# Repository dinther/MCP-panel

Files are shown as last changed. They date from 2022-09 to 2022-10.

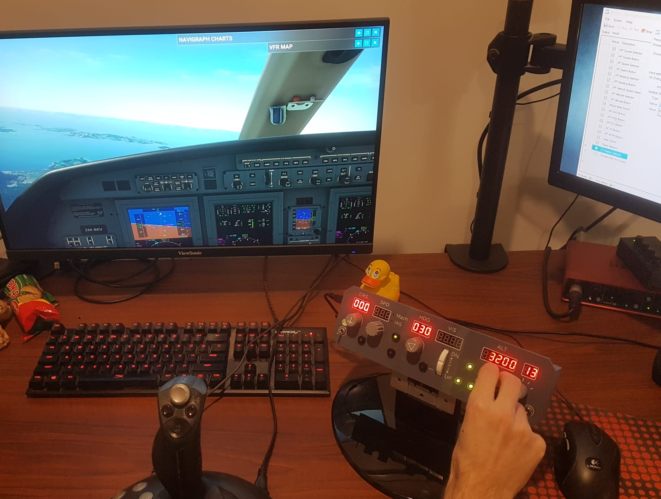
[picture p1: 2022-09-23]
images/panel_in_use_on_cj4_in_msfs2020.jpg

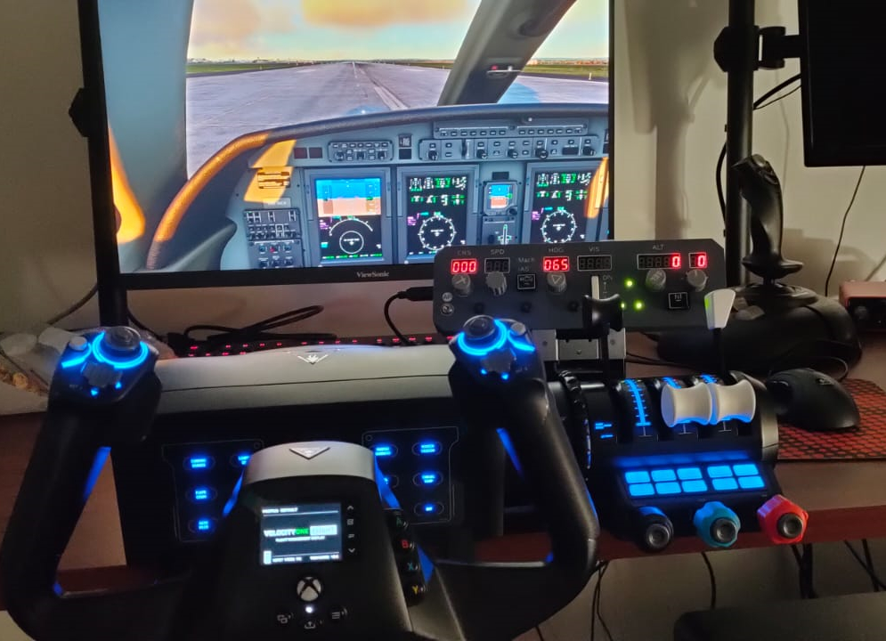
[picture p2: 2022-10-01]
images/Microsoft Flight simulator flying the custom CJ4.jpg

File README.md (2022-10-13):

# MCP-panel

This project shows how to make a control panel with various switches, displays and encoders that can be used in conjuction with Microsoft Flight simulator or other flight simulator programs such as XPlane or DCS (Combat Flight Simulator)

You can write your own software interface or save yourself the pain and simply use the excellent free and open source Mobiflight software https://www.mobiflight.com/
Included in the project is a complete mobiflight definition file for Microsoft Flight Simulator and the cudstom CJ4 aircraft.





3D print your own MCP panel for flight simulator.



Actual printed panels.



## wiring

I wired all switches and encoders to pull the input pin down to ground. This means that the arduino input pins are configured to "INPUT_PULLUP" in mobiflight.

## Hardware used

For convenience I sourced my parts from a local electronics store. Not cheap but I link it here so you can get the details of the parts and source them where you wish.

### Arduino Mega

The one I used is a clone but Mobiflight recognized it without any issues.



https://www.jaycar.co.nz/duinotech-mega-2560-r3-board-for-arduino/p/XC4420

### Segmented displays
I used three 8 digit 7 segment displays. They only had red ones but ideally you want white ones.
The panel is designed to accomodate these displays but these parameters can be changed in OpenSCAD.
You only need three outputs for the all the displays as they are linked.



Tip: Pick the ones where the two display componets are soldered on straight. I noticed many of these displayed online are crooked. However, I did design in some leeway in the 3D panel to accomodate this.

https://www.jaycar.co.nz/8-digit-7-segment-display-module/p/XC3714

### Tactile push buttons
These momentary pushbuttons have build in LED's in red, green and blue. They are small and cheap and with a 3D printed custom face attached they can show whatever back-lit caption you want. The panel has slots designed for 5 of these buttons that should fit tight.


https://www.jaycar.co.nz/spst-pcb-mount-tactile-switch-with-green-led/p/SP0621

### Rotary encoder

I actually used two types of encoders and the shafts were slightly different. The 5 panel holes are made to take either type. The encoders also have a push button function But the vertical wheel can not access the push button function. You need 3 inputs per LED.



https://www.jaycar.co.nz/rotary-encoder-with-pushbutton/p/SR1230

### Dual color 3mm LED's

The panel has 4 dual color (Red / Green) LED's. One is used behind a back-lit round label and the other three as Landing wheel indicators. You can actually also get Amber if you turn on both Red and Green. You need two outputs per LED



https://www.jaycar.co.nz/tricolour-red-green-orange-3mm-led-4-5-6mcd-round-diffused/p/ZD0249

### Toggle switches

The panel contains two toggle switches. Each switch requiring one input.



https://www.jaycar.co.nz/spdt-sub-miniature-toggle-switch-solder-tag/p/ST0300

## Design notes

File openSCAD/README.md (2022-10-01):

##  OpenSCAD
The cad files are made in openSCAD. https://openscad.org/ This is amazing free open source software where you create 3D cad models using a programming language rather than a user interface.
What makes this appoach amazing is that changes are easily managed as everything is pure code. 

The OpenSCAD UI has a customizer UI built in which can be used to make certain adjustments to the cad models without the need to code.

Nobody should commit his designs to closed source rent software such as fusion360 if at all avoidable.

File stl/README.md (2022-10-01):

## 3D Print instructions

It is best to generate your own STL files using the free and excellent openSCAD open source CAD software because then you can customize things like hole sizes, label captions and 3D print details such as layer heights.

But if not, then here are the details you will need to print these STL's.

### Hole test piece


- Material: same as what you intend to use for the Display panel
- color": any
- Nozzle: 0.4mm
- Layer height: 0.3mm
- Infill: 15%

Start with printing the hole test piece. It is a small object that can be 3D printed quickly. Use it to check if the hole sizes work with the components you have.

### Display lid

The display lid closes the back of the MCP box and is designed to hold the Arduino Mega board. There are pegs that slot into the PCB holes. No screws are required as the wires press onto and hold the board in place.
Print it with the back flat on the build plate.

- Material: PLA (PETG if used in hot environments)
- Color: gray
- Nozzle: 0.4mm
- Layer height: 0.3mm
- Infill: 15%

### Display panel
The main panel is a composite of two material colors. There is the main body in gray and the text and symbol inlays in white.



Load the main body into the slicer and place it with the face (Text side) down on the build plate. Then import the display panel text stl and also place it face down on the build plate.
Align the two objects as accurately as possible.

You can allocate a different extruder to each object. I will write a tutorial later on how to create amazing dual material panel prints later.

- Material: PLA (PETG if used in hot environments)
- Color: gray / white
- Nozzle: 0.4mm
- Layer height: 0.3mm
- Infill: 15%

### Pushbutton caps

In order to get nice captions on your push buttons you can use this 3D model. The base clamps onto a tacktile push button and a cap snaps onto the base with whatever caption you want.



The caps are printed in two different color PLA. The white lettering is actually a solid white surface at the back and ponting at the LED in the push button. This allows the white details to emit some light.



STL file comes with these captions but you can define what ever you want in the openSCAD file.

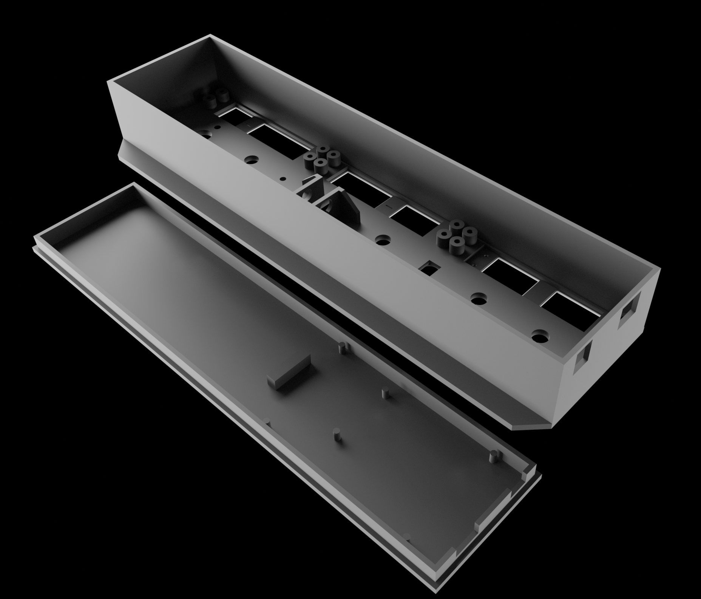
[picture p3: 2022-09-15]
images/display_panel_inside.png

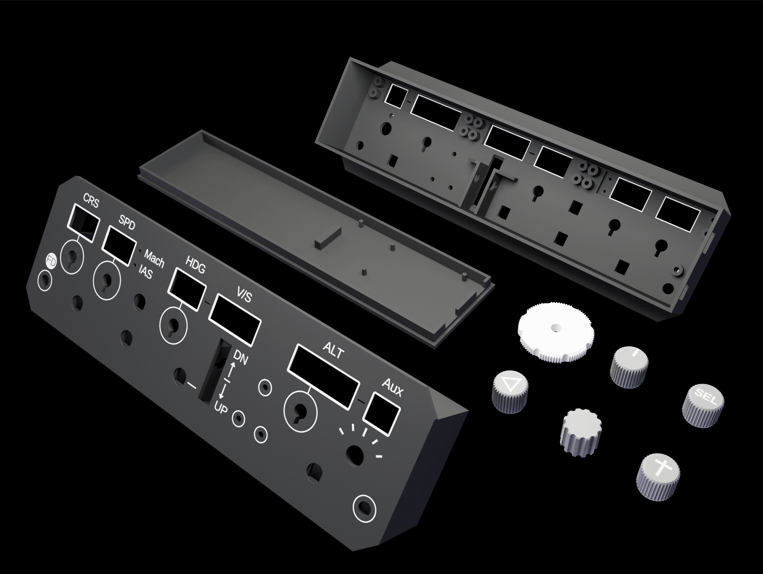
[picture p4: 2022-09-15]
images/display_panel.png

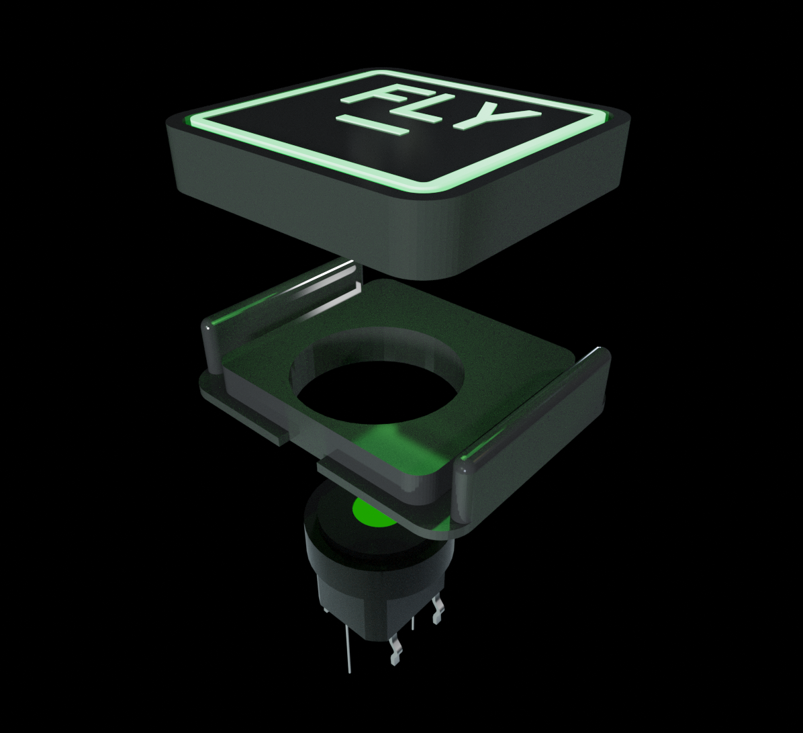
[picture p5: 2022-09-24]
images/pushbutton_cap_system.png

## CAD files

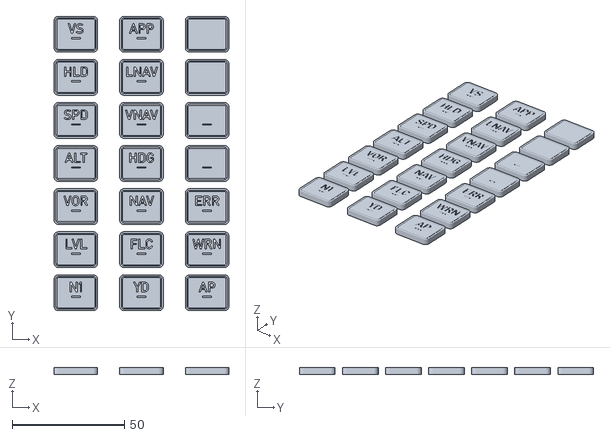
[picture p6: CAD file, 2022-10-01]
stl/MPC_button_caps_0.2_glue_on.stl
78.0 x 131.2 x 2.90

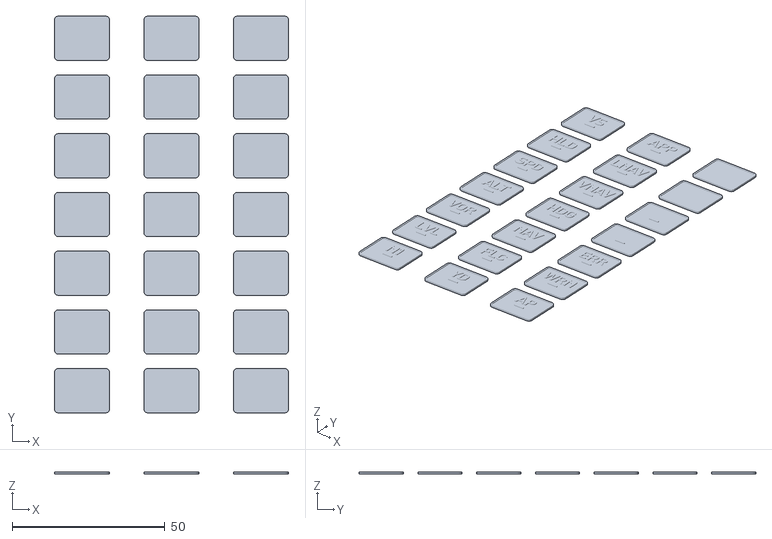
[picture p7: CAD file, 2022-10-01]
stl/MPC_pushbutton_caps_inlay_0.2_glue_on.stl
76.5 x 129.7 x 0.8

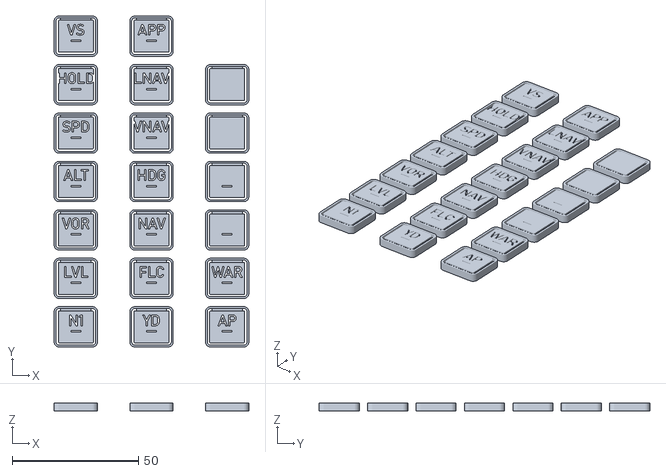
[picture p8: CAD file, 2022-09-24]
stl/MPC_pushbutton_caps.stl
77.2 x 131.2 x 3.10

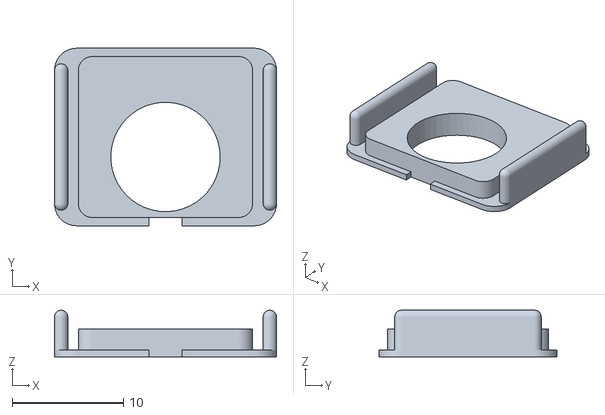
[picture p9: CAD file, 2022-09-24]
stl/MPC_pushbuttons_base.stl
20.0 x 16.0 x 4.20

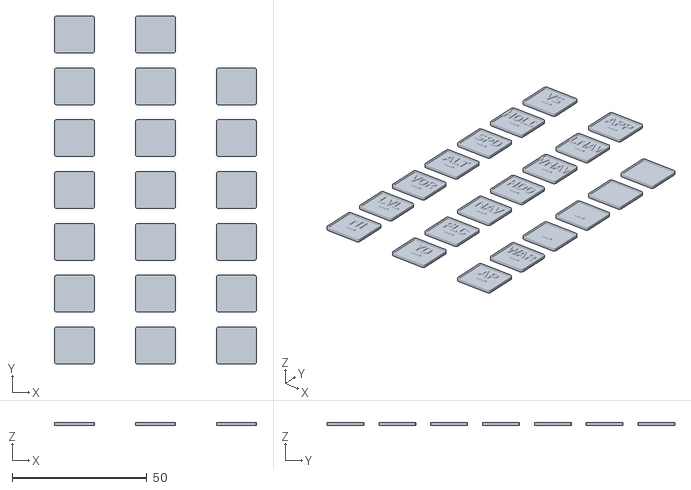
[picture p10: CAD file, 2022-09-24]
stl/MPC_pushbutton_caps_inlay.stl
74.9 x 128.9 x 1.20

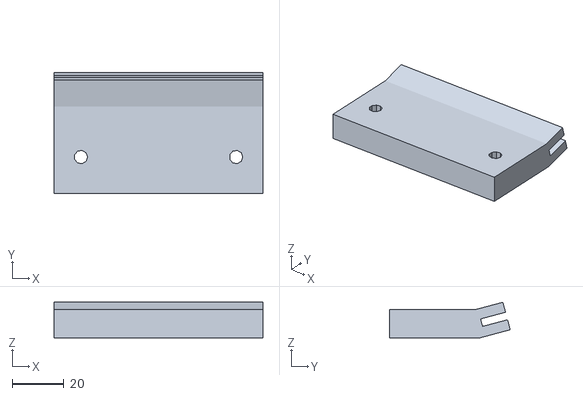
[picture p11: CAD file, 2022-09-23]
stl/mounting_plate_Tom_monitor_stand.stl
80.8 x 46.6 x 13.7

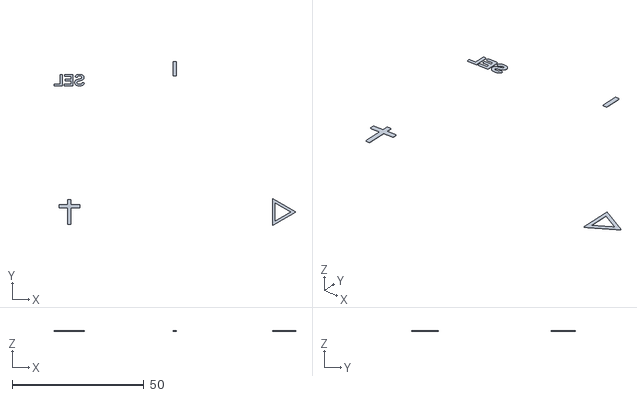
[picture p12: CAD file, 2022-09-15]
stl/MCP_knob_inlays.stl
91.8 x 62.4 x 0.3

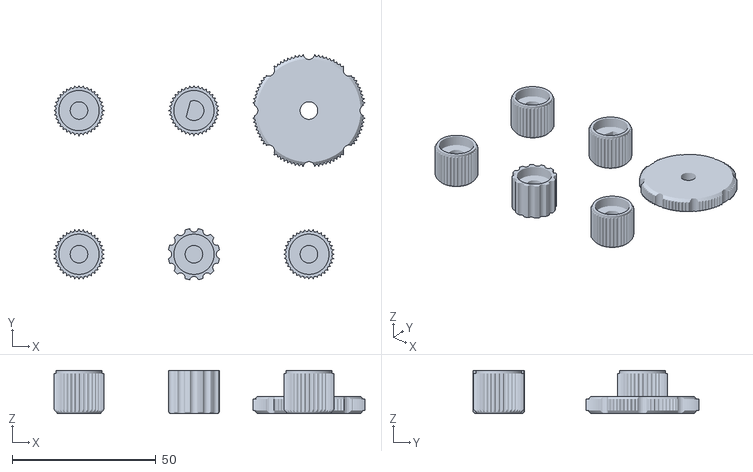
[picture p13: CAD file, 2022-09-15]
stl/MCP_knobs.stl
108.2 x 78.5 x 15.0

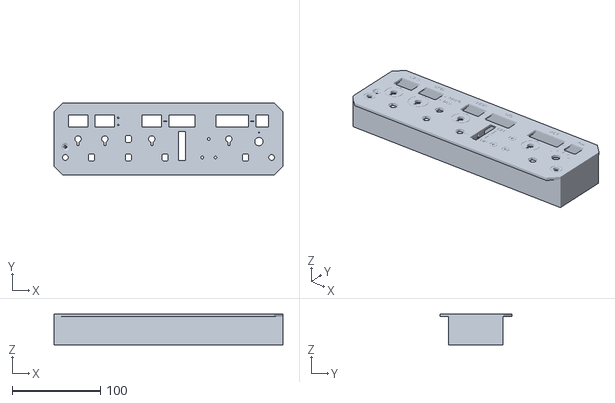
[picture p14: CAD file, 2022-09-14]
stl/display_panel.stl
260.1 x 82.0 x 35.0

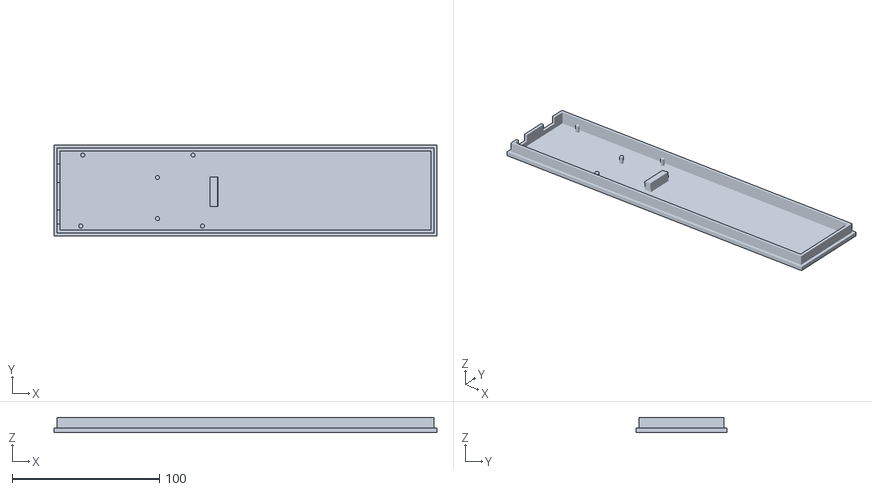
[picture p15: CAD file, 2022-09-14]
stl/display_panel_lid.stl
260.1 x 61.5 x 10.0

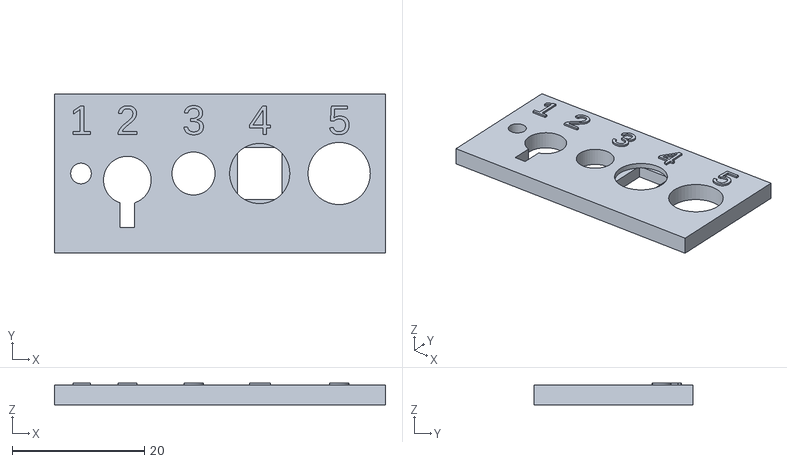
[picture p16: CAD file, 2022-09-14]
stl/hole_test_piece.stl
50.0 x 24.0 x 3.30

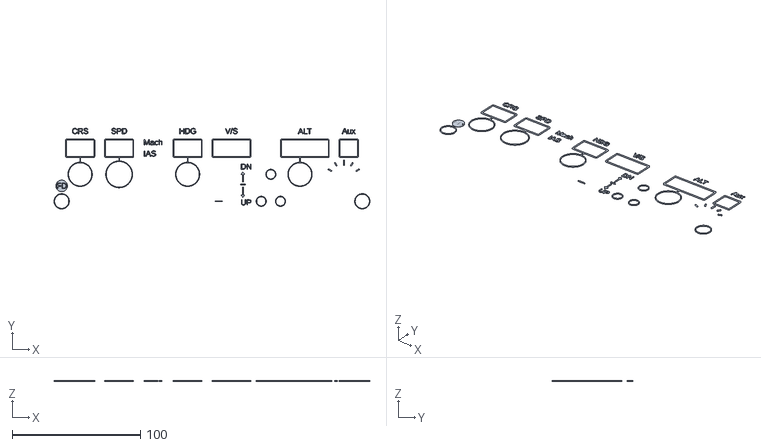
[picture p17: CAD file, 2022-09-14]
stl/display_panel_text.stl
246.1 x 63.1 x 0.6

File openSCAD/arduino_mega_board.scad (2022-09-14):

l = 101.6;
w = 53.3;
t = 1.6;
$fn=45;

module arduino_mega_pcb_holes(diameter = 3.2, height = 1.6){
    translate([13.97, 2.54, 0]) cylinder(d=diameter,h=height);
    translate([15.3, 50.7, 0])  cylinder(d=diameter,h=height);
    translate([66.1, 35.5, 0])  cylinder(d=diameter,h=height);
    translate([66.1, 35.5, 0])  cylinder(d=diameter,h=height);
    translate([66.1, 7.6, 0])   cylinder(d=diameter,h=height);
    translate([90.2, 50.7, 0])  cylinder(d=diameter,h=height);
    translate([96.52, 2.52, 0]) cylinder(d=diameter,h=height);
}

module arduino_mega_pcb(){
    b = 2.8;
    difference(){
        linear_extrude(t) polygon([[0,0],[l-b,0],[l-b,1],[l,1 + b],[l,1 + b + 35],[l-b, 1 + b + 35 + b],[l-b,w-2],[l-b-2,w],[0,w]]);
        //  PCB holes
        translate([0,0,-1]) arduino_mega_pcb_holes(3.2, t + 2);
    }
}

module arduino_mega_headers(){
    translate([17.6,w-3.9,t]) cube([25.6, 2.3, 8.9]);
    translate([44.6,w-3.9,t]) cube([20.5, 2.3, 8.9]);
    translate([67,w-3.9,t]) cube([20.5, 2.3, 8.9]);
    
    translate([26.1,1.8,t]) cube([20.5, 2.3, 8.9]);
    translate([49,1.8,t]) cube([20.5, 2.3, 8.9]);
    translate([72.3,1.8,t]) cube([20.5, 2.3, 8.9]);
    
    translate([93,6.4,t]) cube([4.8,45.9, 8.9]);
    
    translate([15.1,w-9.6,t]) cube([7.2, 5, 8.9]);
    translate([62.5, 24.6,t]) cube([5, 7.2, 8.9]);   
}

module arduino_mega_components(){
    //  cpu
    translate([43.1,21.3,t]) color("#111111") cube([13.4, 13.4, 1.3]);
    //  button
    translate([70.8,24.8,t]) color("silver") cube([6.3, 6.3, 2.1]);
    translate([73.95,27.95,t+2.1]) color("red") cylinder(d = 2.8, h = 0.9);
}

module arduino_mega_USB_plug(){
    translate([-6.3,32.3,t]) color("silver") cube([16.1,12,10.6]);
}

module arduino_mega_USB_plug_cut(){  //  0.5mm oversized for hole cutting
    translate([-6.3,32.05,t-0.25]) color("silver") cube([16.1,12.5,11.1]);
}

module arduino_mega_DC_plug_cut(){  //  0.5mm oversized for hole cutting
    translate([-4.7,3.95,t-0.25]){ cube([6,9.3,11.1]); }    
}

module arduino_mega_DC_plug(){
    color("#111111") difference(){
        union(){
            translate([-1.7,4.2,t]){ cube([13.6,8.8,6.2]); cube([3,8.8,10.6]); }
            translate([-1.7,8.6,t+6.2]) rotate([0,90,0]) cylinder(d=8.8, h=13.6);
        }
        translate([-1.71,8.6,t+6.2]) rotate([0,90,0]) cylinder(d=6.2, h=11.6);
    }
    translate([1,8.6,t+6.2]) rotate([0,90,0]) color("silver") cylinder(d=1.3, h=8);
}

module arduino_mega(){
    color("blue") arduino_mega_pcb();
    color("#111111") arduino_mega_headers();
    arduino_mega_USB_plug();
    arduino_mega_DC_plug();
    arduino_mega_components();
}

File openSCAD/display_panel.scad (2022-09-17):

use <standard_holes.scad>;
use <arduino_mega_board.scad>;
include <8_digit_7_segment_max9219_display_module.scad>;

/* [General] */
$fn = 45;
// distance between the face plate and back wall
depth = 35;
//  Face plate thickness
thickness = 3;
//  Thickness of side walls
wall = 2;
font = "Bahnschrift:style=Light";
//font = "Liberation Sans:style=Normal";
//font = "Liberation Sans:style=Light";
//font = "Liberation Sans:style=Bold";
//  Height of the text font. Beware of 3D printer limitations.
text_size = 4.5;
//  layer height you intend to use for the slicer.
layer_height = 0.3;
//  Thickness of inlay in terms of print layers.
face_layers = 2;

/* [Text labels] */
display_1_text = "CRS";
display_2_text = "SPD";
display_3_text = "HDG";
display_4_text = "V/S";
display_5_text = "ALT";
display_6_text = "Aux";
lit_panel_text = "FD";
display_led_1_text = "Mach";
display_led_2_text = "IAS";
vertical_wheel_top_text = "DN";
vertical_wheel_bottom_text = "UP";


/* [Render] */
show_panel = true;
show_lid = true;
show_inlay = true;
show_hole_test = true;

/* [hidden] */
spacing = 23.0;
row_spacing = 13;
bottom_row = 10;
left_margin = 16;
right_margin = 16;
display_base = 44;
height = 72;
ridge = 0.35;

// 1 - digit, 0 - blank, 2 - two led's, 3 - minus sign only
display_slots_1 = [1,1,1,0,1,1,1,2];  //  CRS, SPD, Mach/IAS
display_slots_2 = [1,1,1,3,1,1,1,1];  //  HDG, V/S
display_slots_3 = [1,1,1,1,1,3,1,1];  //  ALT, Aux

//  helpful modules
module rsquare(s= [1,1], r=0.2, offset=0){
    x = s[0]*0.5;
    y = s[1]*0.5;
    offset(delta = offset)
    hull(){
        translate([-x,-y]) translate([r,r]) circle(r=r);
        translate([-x,y]) translate([r,-r]) circle(r=r);
        translate([x,y]) translate([-r,-r]) circle(r=r);
        translate([x,-y]) translate([-r,r]) circle(r=r);
    }
}

module ring(d1, d2){
    difference(){
        circle(d=d1);
        circle(d=d2);
    }
}

module tube(d1, d2, h){
    linear_extrude(h) ring(d1, d2);
}

module anglebracket(hole){
    t = 2;
    s = 8.5;
    d = 16;
    translate([-d*0.5, -s-t-t, 0]){
        difference(){
            translate([-12,0,0]) cube([t+d+t+12,s+t+t,s+t+t+1]);
            translate([t-14,-0.01,-0.01]) cube([d+14,s+t,s+t+4]);
            translate([-1,0,6]) rotate([40,0,0]) cube(d*2);
            translate([d*0.5+t,s+t-1,9]){
               if (is_num(hole) && (hole > 0)){
                   rotate([-90,0,0]) cylinder(d=hole, h=t*2);
               } else {
                   rotate([-90,180,0]) encoder_hole(thickness, 0.3);
               }
            }
        }
    }
}

module cut_out_shape(){
            fm = 0;
    union(){
        text_y = 4;
        //  display 1
        translate([left_margin + digit_width * 1.5, display_base+digit_height + text_y, 0])
        text(text = display_1_text, font = font, size = text_size, valign = "bottom", halign = "center");
        translate([left_margin + digit_width * 1.5, display_base + digit_height * 0.5, 0]) difference(){
            rsquare(s= [fm + digit_width * 3, fm + digit_height], r=1, offset=0);
            rsquare(s= [fm + digit_width * 3, fm + digit_height], r=1, offset=-0.75);
        }
        
        //  display 2
        translate([left_margin + digit_width * 5.5, display_base+digit_height + text_y, 0])
        text(text = display_2_text, font = font, size = text_size, valign = "bottom", halign = "center");
        translate([left_margin + digit_width * 5.5, display_base + digit_height * 0.5, 0]) difference(){
            rsquare(s= [fm + digit_width * 3,fm + digit_height], r=1, offset=0);
            rsquare(s= [fm + digit_width * 3,fm + digit_height], r=1, offset=-0.75);
        }
        
        //  display 3
        translate([left_margin + display_outer_width + spacing + digit_width * 1.5, display_base + digit_height + text_y, 0])
        text(text = display_3_text, font = font, size = text_size, valign = "bottom", halign = "center");
        translate([left_margin + display_outer_width + spacing + digit_width * 1.5, display_base + digit_height * 0.5, 0]) difference(){
            rsquare(s= [fm + digit_width * 3,fm + digit_height], r=1, offset=0);
            rsquare(s= [fm + digit_width * 3,fm + digit_height], r=1, offset=-0.75);
        }
        
        //  display 4
        translate([left_margin + display_outer_width + spacing + digit_width * 6, display_base + digit_height + text_y, 0])
        text(text = display_4_text, font = font, size = text_size, valign = "bottom", halign = "center");
        translate([left_margin + display_outer_width + spacing + digit_width * 6, display_base + digit_height * 0.5, 0]) difference(){
            rsquare(s= [fm + digit_width * 4,fm + digit_height], r=1, offset=0);
            rsquare(s= [fm + digit_width * 4,fm + digit_height], r=1, offset=-0.75);
        }

        //  display 5
        translate([left_margin + display_outer_width + spacing + display_outer_width + spacing + digit_width * 2.5, display_base + digit_height + text_y, 0])
        text(text = display_5_text, font = font, size = text_size, valign = "bottom", halign = "center");
        translate([left_margin + display_outer_width + spacing + display_outer_width + spacing + digit_width * 2.5, display_base + digit_height * 0.5, 0]) difference(){
            rsquare(s= [fm + digit_width * 5,fm + digit_height], r=1, offset=0);
            rsquare(s= [fm + digit_width * 5,fm + digit_height], r=1, offset=-0.75);
        }
        
        //  display 6
        translate([left_margin + display_outer_width + spacing + display_outer_width + spacing + digit_width * 7, display_base + digit_height + text_y, 0])
        text(text = display_6_text, font = font, size = text_size, valign = "bottom", halign = "center");
        translate([left_margin + display_outer_width + spacing + display_outer_width + spacing + digit_width * 7, display_base + digit_height * 0.5, 0]) difference(){
            rsquare(s= [fm + digit_width * 2,fm + digit_height], r=1, offset=0);
            rsquare(s= [fm + digit_width * 2,fm + digit_height], r=1, offset=-0.75);
        }

        //  vertical wheel labels
        translate([left_margin + display_outer_width + spacing + digit_width * 7.5, display_base-row_spacing+6, 0])
        text(text = vertical_wheel_top_text, font = font, size = text_size, valign = "center", halign = "center");

        translate([left_margin + display_outer_width + spacing + digit_width * 7.5, display_base-row_spacing-22, 0])
        text(text = vertical_wheel_bottom_text, font = font, size = text_size, valign = "center", halign = "center");
        
        //  arrow up down
        translate([left_margin + display_outer_width + spacing + digit_width * 7.5 -2.5, display_base-row_spacing-8, 0])
        polygon([[-0.3,2],[-0.3,8], [-1.5,8],[0,10],[1.5,8],[0.3,8],[0.3,2]]);
        translate([left_margin + display_outer_width + spacing + digit_width * 7.5 -2.5, display_base-row_spacing-8, 0])
        polygon([[-0.3,-2],[0.3,-2],[0.3,-8],[1.5,-8],[0,-10],[-1.5,-8],[-0.3,-8]]);
        translate([left_margin + display_outer_width + spacing + digit_width * 7.5 -4.5, display_base-row_spacing-8.3, 0])
        square([4,0.6]);


        //  display LED top
        translate([left_margin + display_outer_width, display_base + digit_height - 2.55, 0])
        text(text = display_led_1_text, font = font, size = text_size, valign = "center", halign = "left");

        //  display LED bottom
        translate([left_margin + display_outer_width, display_base + 3.15, 0])
        text(text = display_led_2_text, font = font, size = text_size, valign = "center", halign = "left");

        //  Lit panel text
        translate([13, bottom_row + 12, thickness - 0.6])
        difference(){
            circle(d=9);
            text(text = lit_panel_text, font = font, size = text_size, valign = "center", halign = "center");
        }
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

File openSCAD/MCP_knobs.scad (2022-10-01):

/* [General] */
$fn = 90;
outer_radius = 8;
shaft_radius = 3.06; //still to print and try
knob_height = 15;
layer_height = 0.15;
nut_cutout_height = 4;
nut_radius = 7.0;

ribble_radius = 0.5;
font = "Liberation Sans:style=Bold";
Altitude_caption = "SEL";
body_color = "silver"; //"whitesmoke";
inlay_color = "white"; //"dimgray";

/* [Render] */
Show_knobs = true;
Show_inlays = true;

module cap_carve(radius, x = 1.5, y = 1.5){
    difference(){
        translate([0,0,-1])color(body_color)cylinder(r=radius + 2, h=y+1);
         color(body_color)cylinder(r1=radius - x, r2=radius, h=y+0.01);
    }
}

module base_knob(radius, shaft, height, texture){
    difference(){
        union(){
            difference(){
                color(body_color) cylinder(r=radius, h=height);  //  body
                translate([0,0,3.0]) cylinder(r=shaft, h=height);    //  cut shaft
                translate([0,0,height - nut_cutout_height]) cylinder(r=nut_radius, h=nut_cutout_height+1);           //  cut space for nut
                
                if (texture == "carved"){
                    for (i =[0:30:360]) rotate([0,0,i]) translate([radius+0.25,0,0]) color(body_color) cylinder(r=ribble_radius*3, h=height, $fn=32);
                }
            }
            if (texture == "ribble"){
                for (i =[0:10:360]) rotate([0,0,i]) translate([radius+0.2,0,0]) color(body_color)cylinder(r=ribble_radius, h=height-1, $fn=3);
            }
        }
        translate([0,0,0]) cap_carve(radius+2, 2.5, 3);
    }
}

module selector_knob(radius, shaft, height){
    difference(){
        base_knob(radius = radius, shaft = 0, height = height, texture = "ribble");
        translate([0,0,height - nut_cutout_height]) cylinder(r=nut_radius, h=nut_cutout_height+1);
        translate([0,0,-0.1]) selector_decal(outer_radius, 0.1 + layer_height * 2);
        translate([0,0,3.0]) {
            //  Cut D shaft hole
            rotate([0,0,165]) intersection(){
                cylinder(r=shaft, h=height);    //  re-cut shaft
                translate([-shaft,-shaft,0]) cube([5.5, shaft *2, height+1]);
            }
        }
    }
}

module selector_decal(radius, height){
    difference(){
        color(inlay_color) translate([-1.3*0.5,outer_radius * 0.2, 0]) cube([1.3,outer_radius * 0.7, height]);
    }
}

module heading_knob(radius, shaft, height){
    difference(){
        base_knob(radius = radius, shaft = shaft, height = height, texture = "ribble");
        translate([0,0,-0.1]) heading_decal(outer_radius, 0.1 + layer_height * 2);
    }
}

module heading_decal(radius, height){
    difference(){
        color(inlay_color) cylinder(r=radius-2, h=height, $fn=3);
        translate([0,0,-1]) color(inlay_color) cylinder(r=radius-4, h=height+2, $fn=3);
    }
}

module course_knob(radius, shaft, height){   
difference(){
        base_knob(radius = radius, shaft = shaft, height = height, texture = "ribble");
        translate([0,0,-0.1]) course_decal(outer_radius, 0.1 + layer_height * 2);
    }
}

module course_decal(radius, height){
    w = 1.3;
    color(inlay_color) union(){
        translate([-outer_radius* 0.5,outer_radius * 0.2, 0]) cube([outer_radius, w, height]);
        translate([-w*0.5,- outer_radius * 0.6, 0]) cube([w,outer_radius * 1.2, height]);
    }
}

module altitude_knob(radius, shaft, height){
    difference(){
        base_knob(radius = radius, shaft = shaft, height = height, texture = "ribble");
        translate([0,0,-0.1]) altitude_decal(outer_radius, 0.1 + layer_height * 2, Altitude_caption);
    }
}

module altitude_decal(radius, height, text="SEL"){
    color(inlay_color) mirror([1,0,0]) linear_extrude(height) text(text=text, font = font, size=4.5, valign="center", halign="center");
}

module IAS_knob(radius, shaft, height){
    base_knob(radius = radius + 1, shaft = shaft, height = height, texture = "carved");
}


module VS_knob(radius, shaft, height, standoff=0){
    union(){
        difference(){
            union(){
                cylinder(r=radius, h=height);
                //  standoff
                cylinder(r=shaft +1, h=height + standoff); 
                for (i =[0:4:360]) rotate([0,0,i]) translate([radius+0.2,0,0]) cylinder(r=ribble_radius, h=height, $fn=3);   
            }
            for (i =[0:45:360]) rotate([0,0,i]) translate([radius+0.75,0,-0.5]) cylinder(r=ribble_radius*4, h=height+1, $fn=16);
            translate([0,0,0]) cap_carve(radius, 1, 1);
            translate([0,0,height]) rotate([180,0,0]) cap_carve(radius, 1, 1);
            translate([0,0,-1]) cylinder(r=shaft, h=height+2);
        }
        
    }
}

module knobs(){
    row = 50;
    col = 40;
    translate([col * 0, row * 0, 0]) course_knob(radius = outer_radius, shaft = shaft_radius, height = knob_height);
    translate([col * 1, row * 0, 0]) IAS_knob(radius = outer_radius, shaft = shaft_radius, height = knob_height);
    translate([col * 2, row * 0, 0]) heading_knob(radius = outer_radius, shaft = shaft_radius, height = knob_height);
    translate([col * 0, row * 1, 0]) altitude_knob(radius = outer_radius, shaft = shaft_radius, height = knob_height);
    translate([col * 1, row * 1, 0]) selector_knob(radius = outer_radius, shaft = shaft_radius + 0.4, height = knob_height);

    translate([col * 2, row * 1, 0]) VS_knob(radius = 19, shaft = shaft_radius, height = 6, standoff=1);
}

module inlays(){
    row = 50;
    col = 40;
    translate([col * 0, row * 0, 0]) course_decal(outer_radius, layer_height * 2);
    translate([col * 2, row * 0, 0]) heading_decal(outer_radius, layer_height * 2);
    translate([col * 0, row * 1, 0]) altitude_decal(outer_radius, layer_height * 2, Altitude_caption);
    translate([col * 1, row * 1, 0]) selector_decal(outer_radius, layer_height * 2);
}

if (Show_knobs) {
    knobs();
}
if (Show_inlays){
    inlays();
}

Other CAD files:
openSCAD/mounting_plate_Tom_monitor_stand.scad
openSCAD/8_digit_7_segment_max9219_display_module.scad
openSCAD/MPC_pushbuttons.scad
openSCAD/SPST_PCB_Mount_Tactile_Switch_with_LED.scad
openSCAD/standard_holes.scad

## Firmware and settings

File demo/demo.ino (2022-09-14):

//  MCP panel stand-alone demo
//  By: Paul van Dinther

//We always have to include the library
#include "LedControl.h"
#include "encoder.h"

#define DEBOUNCE 2

//  Segmented displays
#define MAX7219CS 22  //  segmented display CS (load) yellow
#define MAX7219CLK 23 //  segmented display CLK (clock) green
#define MAX7219DIN 24 //  segmented display DIN (Data in) black

//  LED's
#define LED1_GREEN 11 //  green LED
#define LED1_RED   12 //  red LED

#define LED2_GREEN 47 //  green LED
#define LED2_RED   46 //  red LED

#define LED3_GREEN 49 //  green LED
#define LED3_RED   48 //  red LED

#define LED4_GREEN 51 //  green LED
#define LED4_RED   50 //  red LED

//  Switches
#define SW1 13        //  switch 
#define SW2 53        //  switch

//  Push buttons
#define PB1_SW  41    //  push button 
#define PB1_LED 40    //  green LED

#define PB2_SW  43    //  push button
#define PB2_LED 42    //  green LED

#define PB3_SW  45    //  push button 
#define PB3_LED 44    //  green LED

#define PB4_SW  39    //  push button
#define PB4_LED 38    //  green LED

#define PB5_SW  37    //  push button 
#define PB5_LED 36    //  red LED

//  Encoders
//  course
#define ENC1A 7       //  encoder A
#define ENC1B 8       //  encoder B
#define ENC1S 6       //  push button

//  speed
#define ENC2A 4       //  encoder A
#define ENC2B 5       //  encoder B
#define ENC2S 3       //  push button

//  heading
#define ENC3A 2       //  encoder A
#define ENC3B 15      //  encoder B
#define ENC3S 14      //  push button

//  vertical speed
#define ENC4A 16      //  encoder A
#define ENC4B 17      //  encoder B
#define ENC4S 18      //  not used

//  altitude
#define ENC5A 19      //  encoder A
#define ENC5B 20      //  encoder B
#define ENC5S 21      //  push button

//  Selector switches
#define SEL0 A0       //  5 position selector switch using voltage divider


/*
 Now we need a LedControl to work with.
 ***** These pin numbers will probably not work with your hardware *****
 pin 12 is connected to the DataIn 
 pin 11 is connected to the CLK 
 pin 10 is connected to LOAD 
 ***** Please set the number of devices you have *****
 But the maximum default of 8 MAX72XX wil also work.
 */
LedControl lc=LedControl(MAX7219DIN,MAX7219CLK,MAX7219CS,3);
Encoder encoder1 = Encoder(ENC1A, ENC1B, ENC1S, 235); 
Encoder encoder2 = Encoder(ENC2A, ENC2B, ENC2S, 210);
Encoder encoder3 = Encoder(ENC3A, ENC3B, ENC3S, 055);
Encoder encoder4 = Encoder(ENC4A, ENC4B, ENC4S, 0);
Encoder encoder5 = Encoder(ENC5A, ENC5B, ENC5S, 27);

byte mode= 10;
byte brightness = 1;
bool caution = true;

/* we always wait a bit between updates of the display */
unsigned long lastTime= millis();

void shownum(byte address, unsigned long n, byte start_digit, byte end_digit, bool leading_zeros){
  unsigned long k=n;
  byte blank=0;
  for(int i=start_digit;i<end_digit;i++){
    if(blank){
      if (leading_zeros)
        lc.setDigit(address,i,0,false);
      else
        lc.setRow(address,i,0x00);
    }else{
      lc.setDigit(address,i,k%10,false);
    }
    k=k/10;
    if(k==0){blank=1;}
  }
}

void showCRS(int n){
  while (n > 360){
    n =- 360;
  }
  while (n < 0){
    n =+ 360;
  }
  shownum(0, n, 5, 8, true);
}

void showSPD(int n, bool mach = false, bool ias = false){
  if (n < 0){ n = 0;}
  shownum(0, n, 1, 4, false);
  lc.setLed(0, 0, 1, mach);
  lc.setLed(0, 0, 4, ias);
}

void showHDG(int n){
  while (n > 360){
    n =- 360;
  }
  while (n < 0){
    n =+ 360;
  }
  shownum(1, n, 5, 8, true);
}

void showVS(int n){
  shownum(1, abs(n), 0, 4, false);
  lc.setLed(1, 4, 7, (n < 0));
}

void showALT(int n){
  if (n < 0){ n = 0;}
  shownum(2, n, 3, 8, false);
}

void showMode(int n){
  if (n < 0){ n = 0;}
  shownum(2, n, 0, 3, false);
}

/* 
 This time we have more than one device. 
 But all of them have to be initialized 
 individually.
 */
void setup() {
  //Serial.begin(9600); // open the serial port at 9600 bps:

  pinMode(SW1, INPUT_PULLUP);
  pinMode(SW2, INPUT_PULLUP);

  pinMode(LED1_GREEN, OUTPUT);
  pinMode(LED1_RED, OUTPUT);
  pinMode(LED2_GREEN, OUTPUT);
  pinMode(LED2_RED, OUTPUT);
  pinMode(LED3_GREEN, OUTPUT);
  pinMode(LED3_RED, OUTPUT);
  pinMode(LED4_GREEN, OUTPUT);
  pinMode(LED4_RED, OUTPUT);

  pinMode(PB1_SW, INPUT_PULLUP);
  pinMode(PB1_LED, OUTPUT);
  pinMode(PB2_SW, INPUT_PULLUP);
  pinMode(PB2_LED, OUTPUT);
  pinMode(PB3_SW, INPUT_PULLUP);
  pinMode(PB3_LED, OUTPUT);
  pinMode(PB4_SW, INPUT_PULLUP);
  pinMode(PB4_LED, OUTPUT);  
  pinMode(PB5_SW, INPUT_PULLUP);
  pinMode(PB5_LED, OUTPUT);
 
  //we have already set the number of devices when we created the LedControl
  int devices=lc.getDeviceCount();
  
  //we have to init all devices in a loop
  for(int address=0;address<devices;address++) {
    /*The MAX72XX is in power-saving mode on startup*/
    lc.shutdown(address,false);
    /* Set the brightness to a medium values */
    lc.setIntensity(address,brightness + address);
    /* and clear the display */
    lc.clearDisplay(address);
  }

digitalWrite(PB5_LED, caution);

  showCRS(encoder1.getValue()); 
  showSPD(encoder2.getValue(), false, true);
  showHDG(encoder3.getValue());
  showVS(encoder4.getValue());
  showALT(encoder5.getValue()*100);
  showMode(mode);  
}

void loop() { 
  if (encoder1.update(DEBOUNCE)){
    while (encoder1.getValue() < 0){
      encoder1.setValue(encoder1.getValue() + 360);
    }
    while (encoder1.getValue() > 359){
      encoder1.setValue(encoder1.getValue() - 360);
    }
    showCRS(encoder1.getValue());
  }
  if (encoder2.update(DEBOUNCE)){
    if (encoder2.getValue() < 0){
      encoder2.setValue(0);
    }    
    showSPD(encoder2.getValue(), false, true);
  }
  if (encoder3.update(DEBOUNCE)){
    while (encoder3.getValue() < 0){
      encoder3.setValue(encoder3.getValue() + 360);
    }
    while (encoder3.getValue() > 359){
      encoder3.setValue(encoder3.getValue() - 360);
    }
    showHDG(encoder3.getValue());
  }
  if (encoder4.update(DEBOUNCE)){
    showVS(encoder4.getValue()*50);
  }
  if (encoder5.update(DEBOUNCE)){
    if (encoder5.getValue() < 0){
      encoder5.setValue(0);
    }
    showALT(encoder5.getValue()*100);
  }  
  
  int sel1 = round(analogRead(SEL0) / 210); //converts analog input to discrete selection values
  if (sel1 != mode){
    if (sel1==0){
      lc.setIntensity(0,0);
      lc.setIntensity(1,0);
      lc.setIntensity(2,0);
    }
    if (sel1==1){
      lc.setIntensity(0,1);
      lc.setIntensity(1,2);
      lc.setIntensity(2,3);
    }
    if (sel1==2){
      lc.setIntensity(0,3);
      lc.setIntensity(1,5);
      lc.setIntensity(2,6);
    }
    if (sel1==3){
      lc.setIntensity(0,5);
      lc.setIntensity(1,7);
      lc.setIntensity(2,9);
    }        
    if (sel1==4){
      lc.setIntensity(0,7);
      lc.setIntensity(1,12);
      lc.setIntensity(2,15);
    }    
    
    showMode(sel1);
    mode = sel1;
  }

  if (!digitalRead(PB1_SW)){
    digitalWrite(PB1_LED, true);
    digitalWrite(PB2_LED, false);
    digitalWrite(PB3_LED, false);
    digitalWrite(PB4_LED, false);
  }

  if (!digitalRead(PB2_SW)){
    digitalWrite(PB1_LED, false);
    digitalWrite(PB2_LED, true);
    digitalWrite(PB3_LED, false);
    digitalWrite(PB4_LED, false);
  }

  if (!digitalRead(PB3_SW)){
    digitalWrite(PB1_LED, false);
    digitalWrite(PB2_LED, false);
    digitalWrite(PB3_LED, true);
    digitalWrite(PB4_LED, false);
  }  

  if (!digitalRead(PB4_SW)){
    digitalWrite(PB1_LED, false);
    digitalWrite(PB2_LED, false);
    digitalWrite(PB3_LED, false);
    digitalWrite(PB4_LED, true);
  }
    
  if (!digitalRead(PB5_SW)){
    caution = !caution;
    digitalWrite(PB5_LED, caution);
    delay(300);
  }

  digitalWrite(LED1_GREEN,digitalRead(SW1));
  bool state = digitalRead(SW2);
  digitalWrite(LED2_GREEN, state);
  digitalWrite(LED3_GREEN, state);
  digitalWrite(LED4_GREEN, state);
  digitalWrite(LED2_RED, !state);
  digitalWrite(LED3_RED, !state);
  digitalWrite(LED4_RED, !state);  
}

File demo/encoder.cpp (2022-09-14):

//  Basic encoder class
//  By: Paul van Dinther

#include "Arduino.h"
#include "encoder.h"

Encoder::Encoder(int pinA, int pinB, int pinS, int value) {
  pinMode(pinA, INPUT_PULLUP);
  pinMode(pinB, INPUT_PULLUP);
  pinMode(pinS, INPUT_PULLUP);
  _pinA = pinA;
  _pinB = pinB;
  _pinS = pinS;
  _encoder_A = false;
  _encoder_B = false;
  _encoder_S = false;
  _value = value;
  _down = false;
  _lastTime = millis();
}

bool Encoder::update(byte debounce = 2){
  unsigned long currentTime = millis();
  int old_value = _value;
  bool down = _down;
  if(currentTime >= (_lastTime + debounce)){
    _lastTime = currentTime;
    bool encoder_A = digitalRead(_pinA);    // Read encoder pins
    bool encoder_B = digitalRead(_pinB);
    
    if(encoder_A != _encoder_A){
      // A changed
      if(encoder_A != encoder_B) {
        // but B has not yet changed. CW
        _value--;
      }
    }

    if(encoder_B != _encoder_B){
      // B changed
      if(encoder_B != encoder_A) {
        // but A has not yet changed. CCW
        _value++;
      }
    }

    _down = digitalRead(_pinS);

    _encoder_A = encoder_A;
    _encoder_B = encoder_B;
  }
  return _value != old_value;// || down != _down;
}

int Encoder::getValue(){
  return _value;
}

void Encoder::setValue(int value){
  _value = value;
}

bool Encoder::getDown(){
  return _down;
}

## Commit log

2022-09-13 Add files via upload
    Basic Arduino Mega board geometry. Useful to establish fit, mounting point position and to cut holes for the USB and power plug.
    [arduino_mega_board.stl]
2022-09-13 Update arduino_mega_board.scad
    Centered DC bus
    [arduino_mega_board.scad]
2022-09-13 Add files via upload
    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
    [arduino_mega_board.stl]
2022-09-14 moved hole objects to separate unit
    [standard_holes.scad]
2022-09-14 Restructured model code and updated the customizer
    [8_digit_7_segment_max9219_display_module.scad, arduino_mega_board.scad, display_panel.scad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]
2022-09-14 stls rendered by openSCAD source code
    [MPC_pushbuttons.stl, arduino_mega_board.stl, display_panel.scad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]
2022-09-14 Test STL to try component fit.
    [hole_test_piece.stl]
2022-09-14 added numbers to test piece
    [display_panel.scad]
2022-09-14 added index
    [display_panel.scad]
2022-09-14 arduino stand-alone demo code
2022-09-15 added Vertical wheel
    [MCP_knobs.stl]
2022-09-17 button caps
    [MCP_knobs.scad, MPC_pushbuttons.scad, MPC_pushbuttons.stl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]
2022-09-23 Added rail option to the button face model
    [MPC_pushbutton_HDG.stl, MPC_pushbuttons.scad, mounting_plate_Tom_monitor_stand.scad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]
2022-09-24 Cleaned up the code and setup the customizer
    [MPC_pushbuttons.scad]
2022-09-24 model of pushbutton
    [SPST PCB Mount Tactile Switch with LED.scad]
2022-09-24 pushbutton parts
    [MPC_pushbutton_caps.stl, MPC_pushbutton_caps_inlay.stl, MPC_pushbuttons_base.stl]
2022-09-24 Deleted irrelevant
    [MPC_pushbutton_HDG.stl, MPC_pushbuttons.stl]
2022-09-24 model of tactile pushbutton
    [SPST_PCB_Mount_Tactile_Switch_with_LED.scad]
2022-10-01 Improved captions
    [MPC_pushbuttons.scad]
2022-10-01 Tidied up customizer
    [MCP_knobs.scad]
2022-10-01 Added sections to customizer
    [MPC_pushbuttons.scad]
2022-10-01 Stand alone button caps to glue onto switches
    [MPC_button_caps_0.2_glue_on.stl, MPC_pushbutton_caps_inlay_0.2_glue_on.stl]
